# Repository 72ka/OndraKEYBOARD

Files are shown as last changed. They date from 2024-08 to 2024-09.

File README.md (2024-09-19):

# OndraKEYBOARD (Work in progress state!)

 Keyboard replica for the famous czechoslovak home computer [TESLA Ondra SPO186](http://www.ondraspo186.8u.cz/ "Tento web se zabývá československým počítačem Tesla Ondra SPO 186")
 
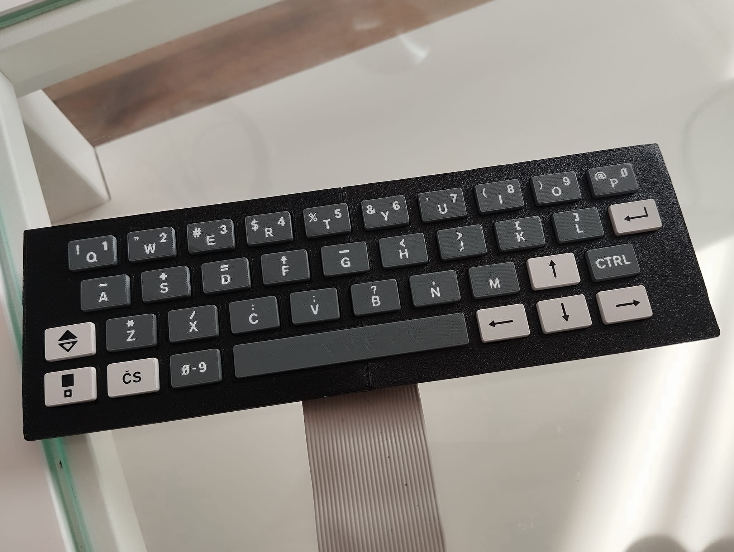
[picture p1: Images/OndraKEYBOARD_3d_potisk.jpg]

> OndraKEYBOARD replica of Tesla TX522xxx keyboard (real photo of complete manual multicolour 3D print on Prusa MINI+ including labels)

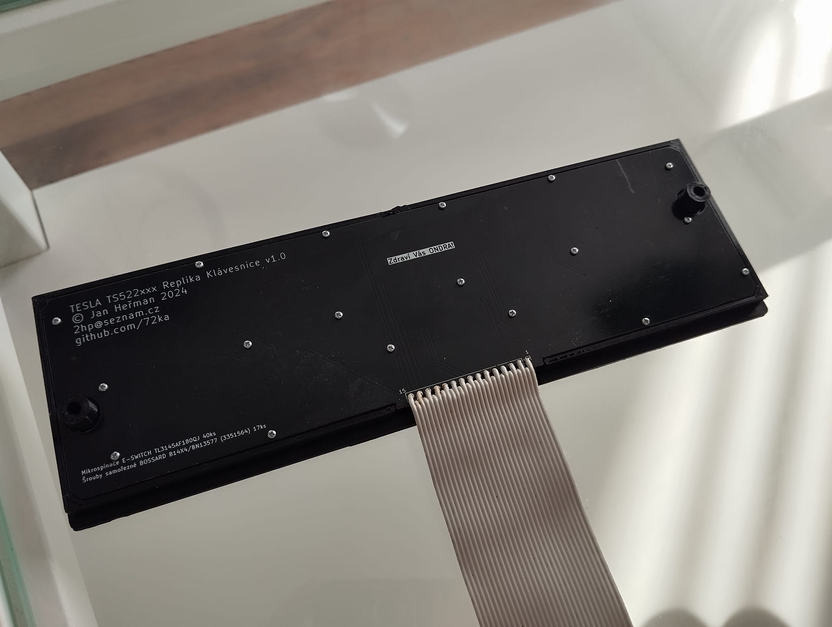
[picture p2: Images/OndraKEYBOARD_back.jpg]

> Back side
> 
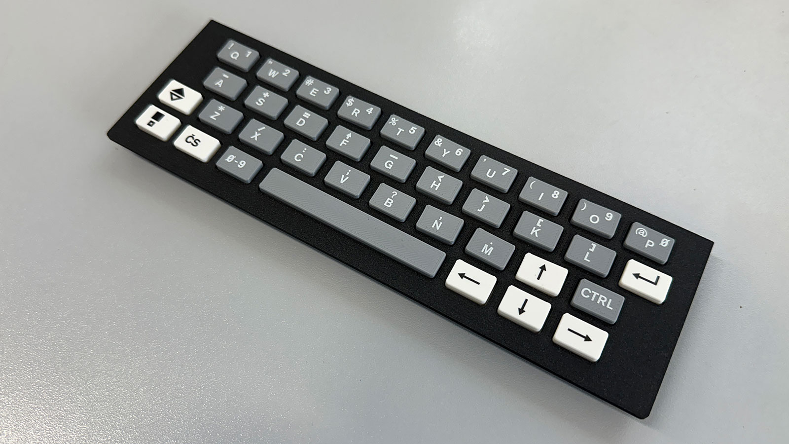
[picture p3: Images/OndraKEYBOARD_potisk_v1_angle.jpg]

> Real photo of early build from Martin8bity.cz, laser printed labels


> Czechoslovak home computer Tesla Ondra SPO186 - introduced in 1985

### Features

- Free to use hardware
- Identical dimensions
- Similar mechanical properties (key force and displacement)
- Modern high grade microswitches E-SWITCH with rubber pin
- Durable
- Acceptable cost around 400CZK for switches
- Designed for home 3D printing
- Designed to buy parts on TME.eu in one banch
- PCB is usable as replacement of original mebrane to original keyboard with some modification

### Build steps

1. Print the buttons stp files using your printer one (without 3D printed labels) or two colors (3D printed labels with 0.25mm nozzle)
2. The keycaps should be printed upside-down with supports
3. The body should be printed on rough printplate to obtain the desired surface like original with your default nozzle (0.4mm)
4. Insert the M2.5 thread inserts into the body (2pcs) using hot end soldering iron pushing to inserts
5. Recommended material is ASA or PETG. PLA is also good enough.
6. Solder all microswitches to PCB (you can omit two center switches on space button)
7. Solder the flat cable to the PCB and bend to 90 degrees
8. On the end of the flat cable solder the pinheader
9. Insert the keycaps to the body
10. Insert the PCB
11. Secure the PCB using the screws
12. Select the technology for keycaps print - professional print, DIY decals, Rub-On Stickers and paint, etc..
13. Done, enjoy, share...

### How to print two-color buttons on Prusa MINI+ 3D printer

1. My selected PLA filaments colors "Spectrum Premium PLA 1.75mm Dark Grey", "Spectrum Premium PLA 1.75mm Light Grey", "Spectrum Premium PLA 1.75mm Arctic White", "Prusament PLA Prusa Galaxy Black"
2. Insert the 0.25mm nozzle to printer
3. Use GCode or slice it by yourself (check all the changes on the PrusaSlicer project file)
4. Critical setting is the Z-axis settings, too much low will affect the sharpness and details in labels, too high affects the finished surface or can cause the print failure
5. Use default PLA teperatures (yes, 60degC on plate even for Spectrum filament)
6. Insert the body colour filament and start print
6. After a while, printer will want to change filament, change it to label colour, clean the nozzle and remove residue. Insert piece of paper on the first print layer and let the printer to "smudge" the nozzle against the paper, it is quick, but this method fixes the unwanted blobs on first layer. Then labels will be printed and again, change the body colour back when the printer wants it and leave it to finish the job

### Recommended parts list (TME.eu)

- 40pc Microswitches - E-SWITCH TL3145AF180QJ (Symbol TME: TL3145AF180QJ)
- 20pc Screws - BOSSARD B14X4/BN13577 (Smybol TME: B14X4/BN13577)
- 2pc  Inserts - BOSSARD 1386735 (Symbol TME: B2.5/BN1054)

### More photos

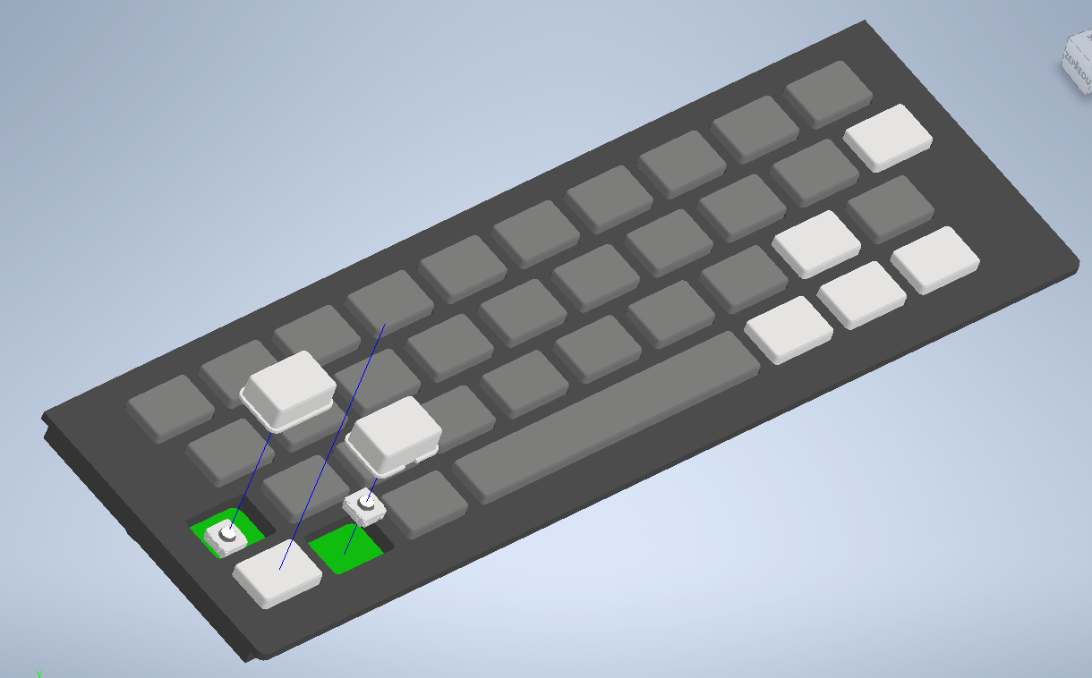
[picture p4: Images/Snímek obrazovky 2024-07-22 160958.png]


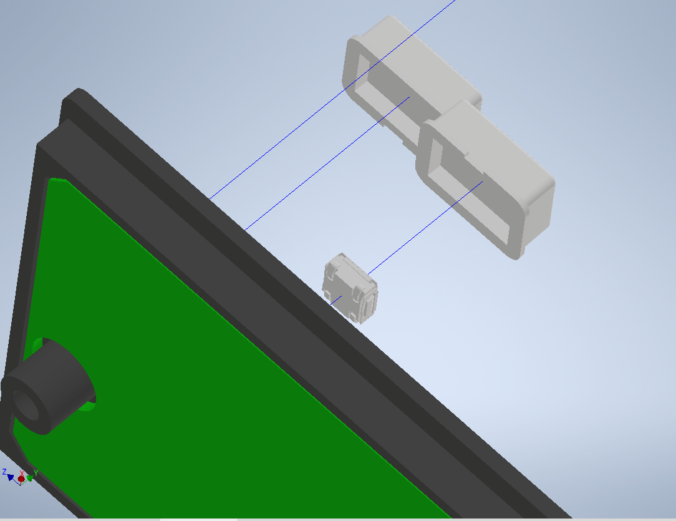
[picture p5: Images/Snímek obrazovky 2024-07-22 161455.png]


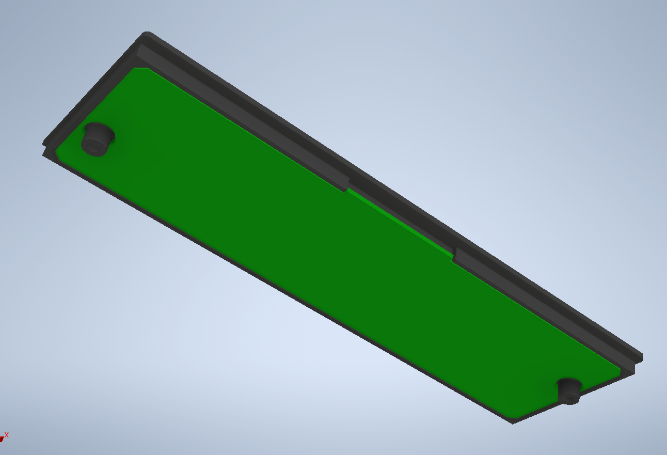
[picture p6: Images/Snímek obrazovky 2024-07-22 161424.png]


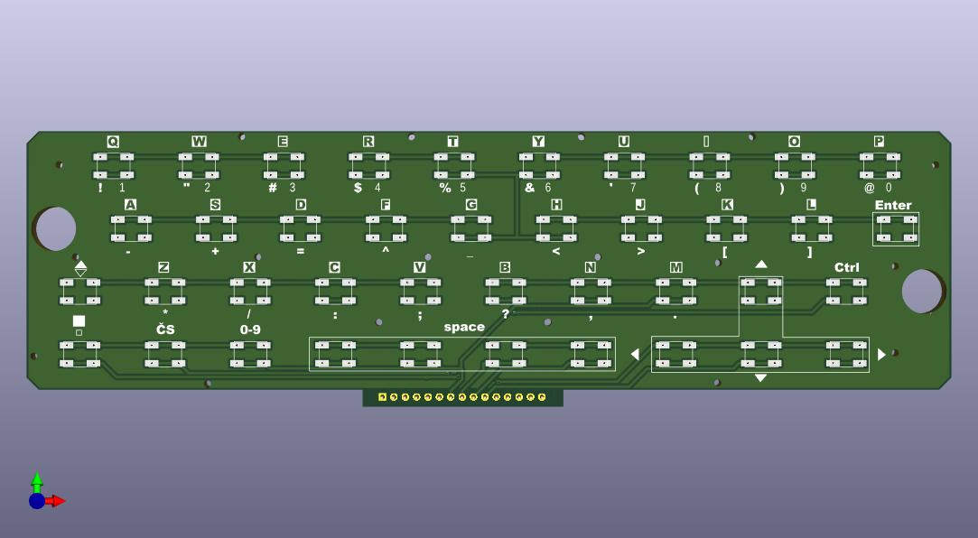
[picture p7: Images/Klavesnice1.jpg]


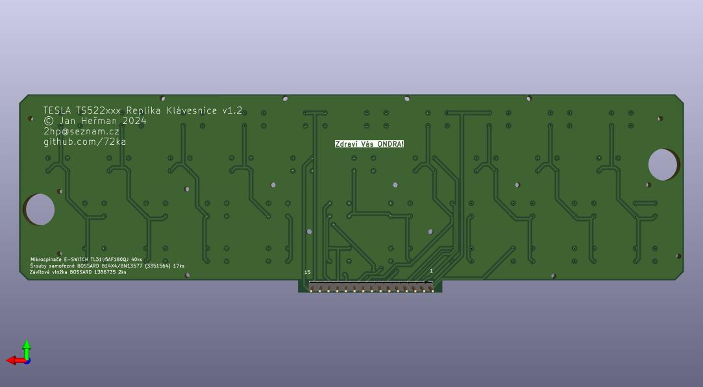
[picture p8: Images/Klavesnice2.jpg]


### License

MIT license

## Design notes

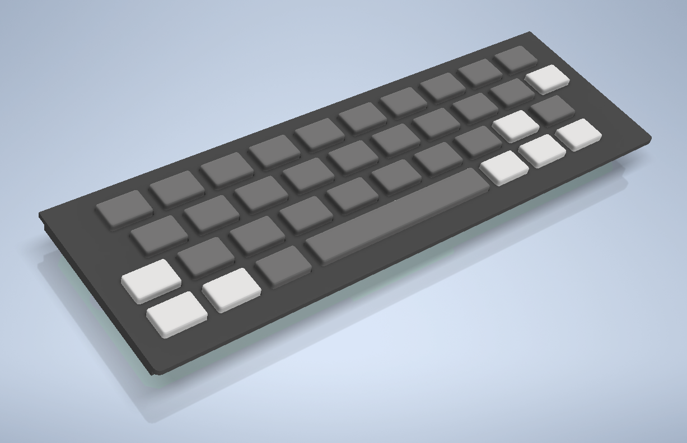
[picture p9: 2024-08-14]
Images/Snímek obrazovky 2024-07-22 161343.png

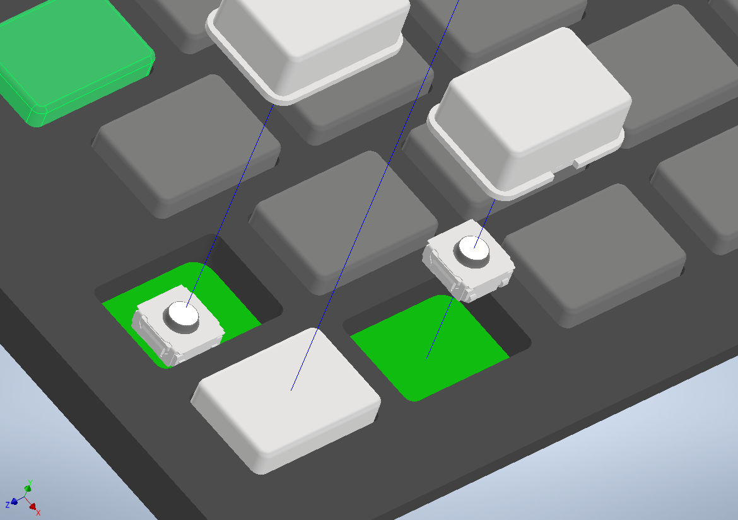
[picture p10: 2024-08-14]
Images/Snímek obrazovky 2024-07-22 161442.png

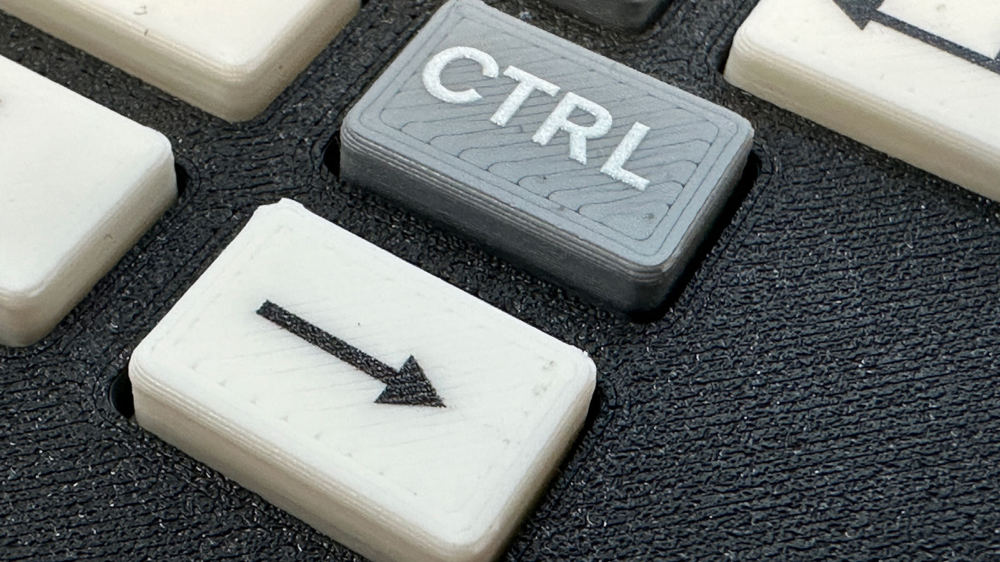
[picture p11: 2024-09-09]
Images/OndraKEYBOARD_potisk_v1_detail.jpg

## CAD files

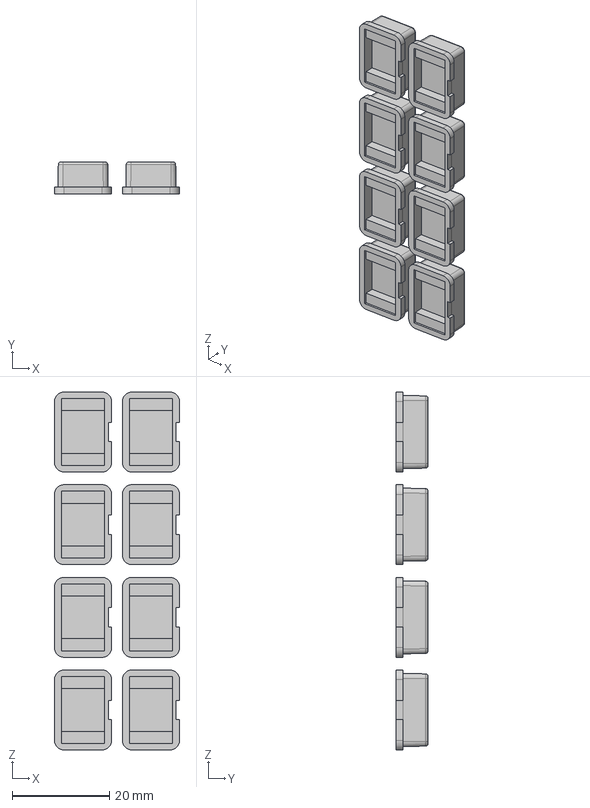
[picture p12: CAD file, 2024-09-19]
CAD/Tisk_tl_svetla_color.stp
25.8 x 6.60 x 73.8 mm
Tlacitko
Tlacitko_1
Tlacitko_2
Tlacitko_3
Tlacitko_4
Tlacitko_5
Tlacitko_6
Tlacitko_7
Potisk_na_svetla_tlacitka

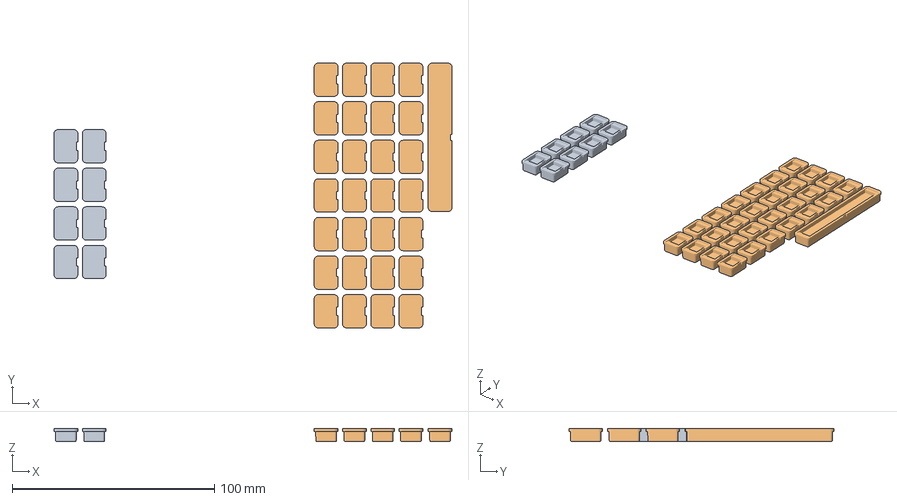
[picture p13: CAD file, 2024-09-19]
PrusaSlicer/Tlacitka_Flat_Or_Color.3mf
197.0 x 131.1 x 6.60 mm
Tisk_tl_svetla_color
Tisk_tl_tmava_color

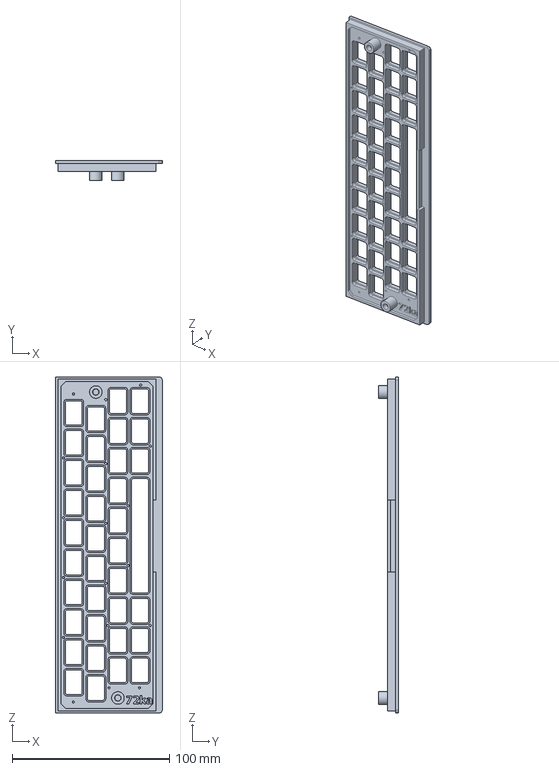
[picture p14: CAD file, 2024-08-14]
CAD/Teleso_klavesnice.stp
67.8 x 13.0 x 213.4 mm

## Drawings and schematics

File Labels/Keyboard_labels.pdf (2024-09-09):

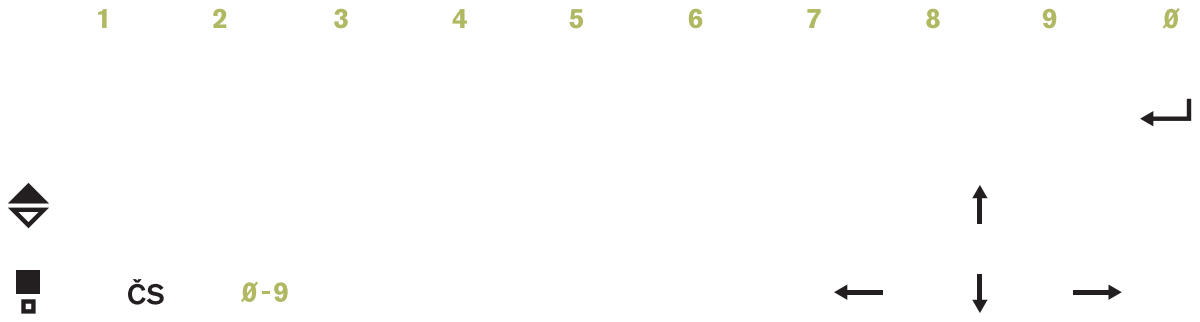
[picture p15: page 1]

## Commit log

2024-08-14 Initial commit
    v1.1
    [Mezernik.stp, Teleso_klavesnice.stp, Tlacitko.stp]
2024-09-02 Add files via upload
    - extended pads for easy soldering
    - vias in pads for more pads strength
    - main connector moved to be outside of keyboard body
2024-09-19 Final design
    Updated to final design, including the 3d printed labels.
    [Mezernik.stp, Tisk_tl_svetla_color.stp, Tlacitka_Flat_Or_Color.3mf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]
2024-09-19 Update d filaments
